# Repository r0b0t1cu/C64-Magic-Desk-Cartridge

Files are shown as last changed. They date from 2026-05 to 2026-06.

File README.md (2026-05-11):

# C64 Magic Desk Cartridge

An open-source hardware clone of the **Magic Desk** cartridge format for the Commodore 64. Supports both **27C512** (64KB) and **29F040** (512KB) EPROMs/EEPROMs, with bank switching handled by a classic 74LS273 + 74LS02 glue logic combination.

This board is designed to be built with through-hole components and DIP sockets, making it easy to assemble, reprogram, and experiment with.

| Front | Back |
|---|---|
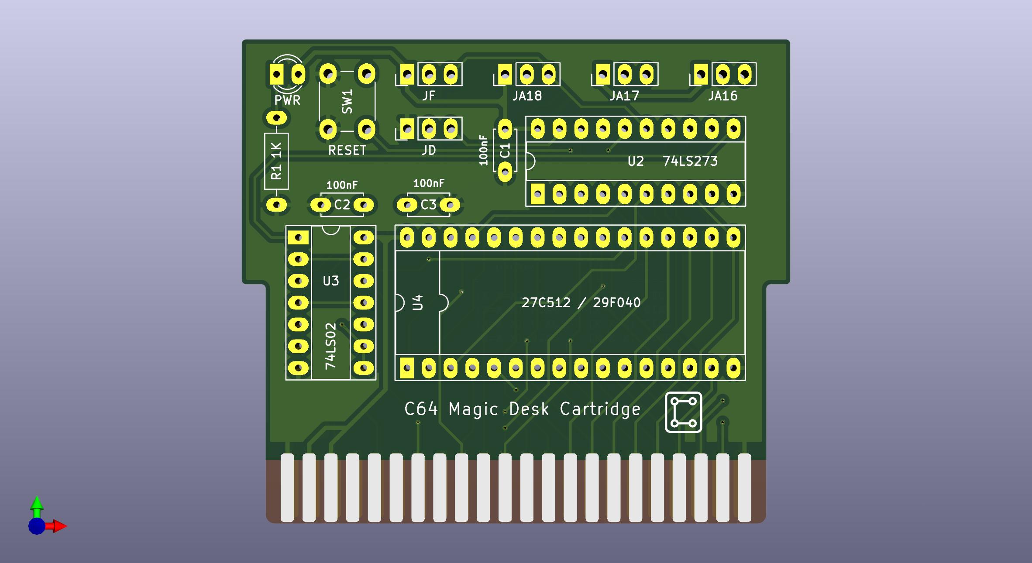
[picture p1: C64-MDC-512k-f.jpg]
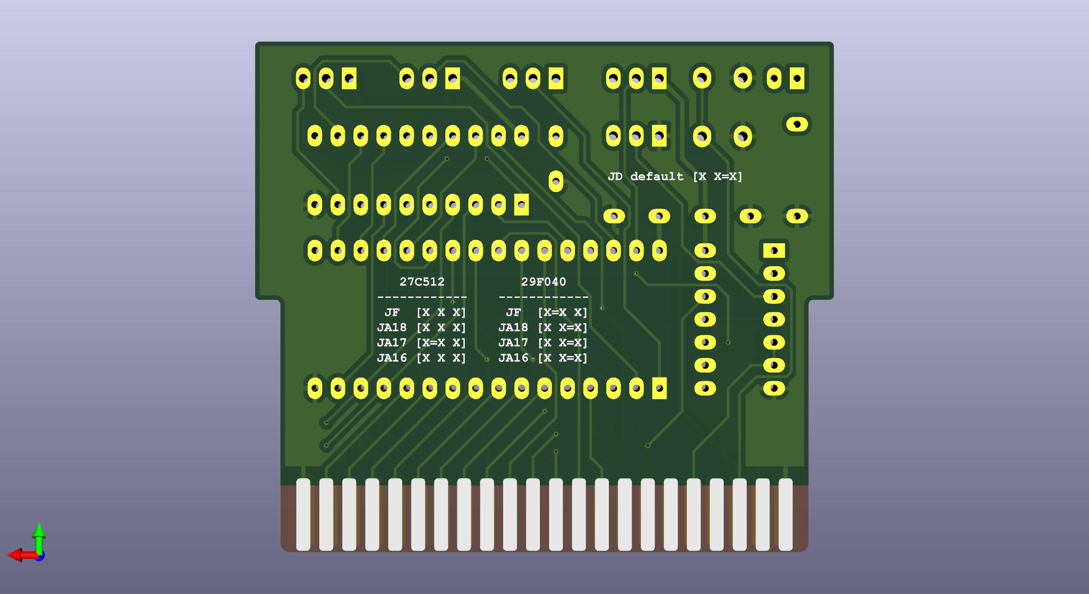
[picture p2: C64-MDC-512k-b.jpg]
|  |  |

---

## What is the Magic Desk Format?

Magic Desk is a simple and well-documented C64 cartridge format originally used by Commodore for titles like *Ghostbusters*, *Winter Games*, and others. It works by bank-switching 8KB ROM banks into the C64's memory map at `$8000`. A single byte write to `$DE00` selects the active bank; bit 7 controls the EXROM line to enable or disable the cartridge.
Because of its simplicity and wide software support, it became a popular format for homebrew multicarts and game compilations.

---

## Features

- Supports **27C512** (64KB) and **29F040** (512KB)
- Standard C64 cartridge edge connector
- DIP sockets for all ICs — easy to swap and reprogram
- PWR LED indicator
- RESET button
- Jumper configuration for ROM type

---

## Bill of Materials

| Ref | Qty | Value | Package |
|-----|-----|---|---|
| C1, C2, C3 | 3 | 100nF | Disc, 5.00mm pitch |
| R1 | 1 | 1K | Axial, horizontal |
| D1 | 1 | LED (PWR) | 3mm |
| U2 | 1 | 74LS273 | DIP-20, socket |
| U3 | 1 | 74LS02 | DIP-14, socket |
| U4 | 1 | 27C512 or 29F040 | DIP-32, socket |
| SW1 | 1 | RESET | Tactile push button 6mm |

---

## Jumper Configuration

The back of the board has a jumper table printed in silkscreen for quick reference. Configure the jumpers according to the ROM you are using:

### JD — default bank select (controls EXROM / cartridge enable)

| JD | Meaning |
|----|---|
| X X=X | Cartridge always enabled |

### Address line jumpers (JF, JA16, JA17, JA18)

These select which address lines are connected, depending on the ROM size installed.

#### 27C512 (64KB)

| Jumper | Setting |
|---|---|
| JF | X X X |
| JA18 | X X X |
| JA17 | X=X X |
| JA16 | X X X |

#### 29F040 (512KB)

| Jumper | Setting |
|---|---|
| JF | X=X X |
| JA18 | X X=X |
| JA17 | X X=X |
| JA16 | X X=X |

> **[X=X]** means the two pads are bridged with a solder jumper or jumper cap. **[X X X]** means left open.

Refer to the silkscreen on the back of the board for the full table.

---

## ROM Images

This repository includes pre-compiled **512KB `.bin` files** ready to be burned directly to a **29F040** EEPROM. Each image is a Magic Desk format multicart containing a curated selection of C64 software.

```
roms/
└── *.bin    # Ready-to-burn 512KB images for 29F040
```

To burn a `.bin` file to a 29F040, use a programmer such as:
- TL866II Plus / T48 (xgecu)
- GQ-4X
- Any EPROM programmer that supports the 29F040

| Front | Back |
|---|---|
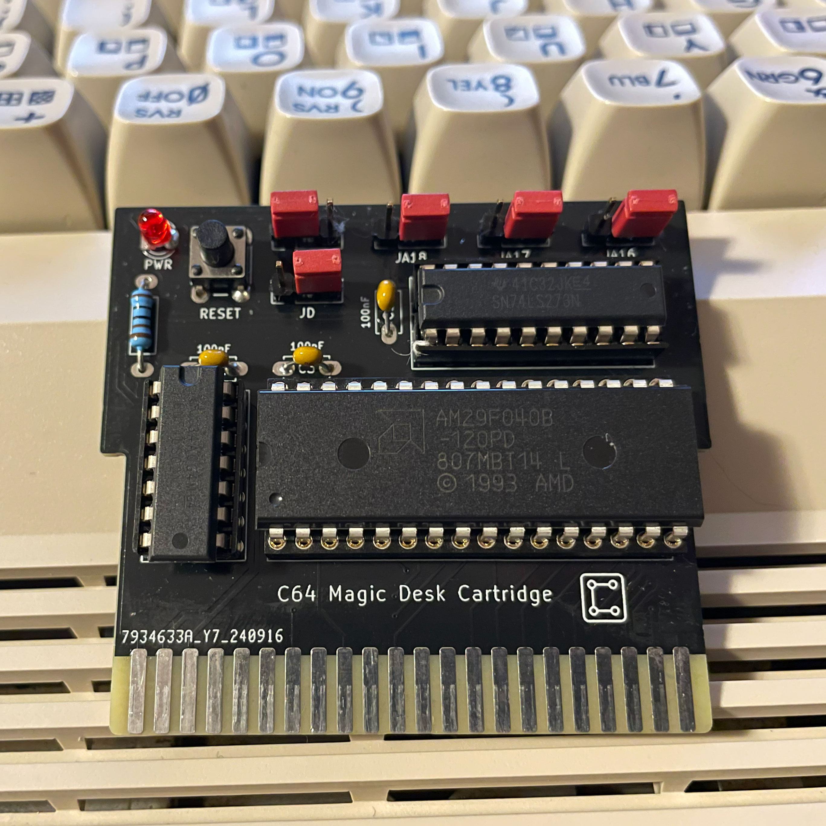
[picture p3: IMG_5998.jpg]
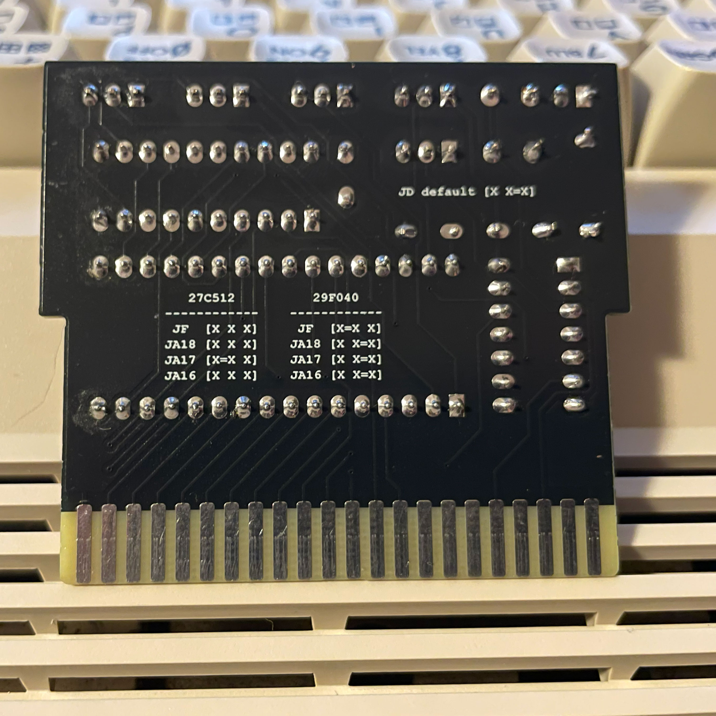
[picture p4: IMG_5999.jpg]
|  |  |

---

## Creating Your Own ROM Image

Use the **Magic Desk Cartridge Generator** by Zzarko to build your own `.bin` files from `.prg` or `.crt` files:

- [Magic Desk Cartridge Generator V3.0](https://csdb.dk/release/?id=179083) — original release
- [Magic Desk Cartridge Generator V3.5](https://csdb.dk/release/?id=205274) — newer version (recommended)
- [Source on Bitbucket](https://bitbucket.org/zzarko/magic-desk-cartridge-generator/)

The generator creates a menu-driven launcher that lets you select titles directly on the C64, with no extra hardware needed.

---

## Building the PCB

1. **Order the PCB** — use the Gerber files in `gerbers/`. Standard 2-layer 1.6mm FR4. JLCPCB, PCBWay, etc.
2. **Solder passives first** — capacitors, resistor, LED.
3. **Solder the edge connector** — take care with alignment; the card edge fingers go toward the bottom.
4. **Solder the DIP sockets** — do not solder ICs directly; use sockets so chips can be swapped.
5. **Configure jumpers** — set JF, JD, JA16, JA17, JA18 for your ROM type before inserting the chip.
6. **Insert ICs** — 74LS273, 74LS02, and your programmed EPROM/EEPROM.
7. **Insert into C64** — power on; the cartridge menu should appear immediately.

---

## Compatibility

Tested on:
- Commodore 64 (breadbin and short board)

Should work on:
- Commodore 64C
- Commodore 128 (in C64 mode)

---

## Related Projects

- [Magic Desk Cartridge Generator V3.5](https://csdb.dk/release/?id=205274) by Zzarko — the tool used to build the ROM images
- [Pi1541-Simple-HAT](https://github.com/r0b0t1cu/Pi1541-Simple-HAT) — Raspberry Pi HAT for Pi1541 disk emulation

---

## License

This project is open-source hardware released under the [CERN Open Hardware Licence v2 - Permissive (CERN-OHL-P)](https://ohwr.org/cern_ohl_p_v2.txt).

The Magic Desk Cartridge Generator is the work of Zzarko / Once Upon A Byte and is licensed separately.

---

## Author

Designed by [r0b0t1cu](https://github.com/r0b0t1cu) — 2026

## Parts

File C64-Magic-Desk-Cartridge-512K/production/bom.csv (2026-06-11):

Designator | Footprint | Quantity | Value | LCSC Part #
C1, C2, C3 | C_Disc_D4.7mm_W2.5mm_P5.00mm | 3 | 100nF
D1 | LED_D3.0mm | 1 | PWR
R1 | R_Axial_DIN0207_L6.3mm_D2.5mm_P10.16mm_Horizontal | 1 | 1K
SW1 | SW_PUSH_6mm | 1 | RESET
U1 | C64_Cart_Edge | 1 | C64 Cartridge Edge Connector
U2 | DIP-20_W7.62mm_Socket_LongPads | 1 | 74LS273
U3 | DIP-14_W7.62mm_Socket_LongPads | 1 | 74LS02
U4 | DIP-32_W15.24mm_Socket_LongPads | 1 | 27C512 / 29F040

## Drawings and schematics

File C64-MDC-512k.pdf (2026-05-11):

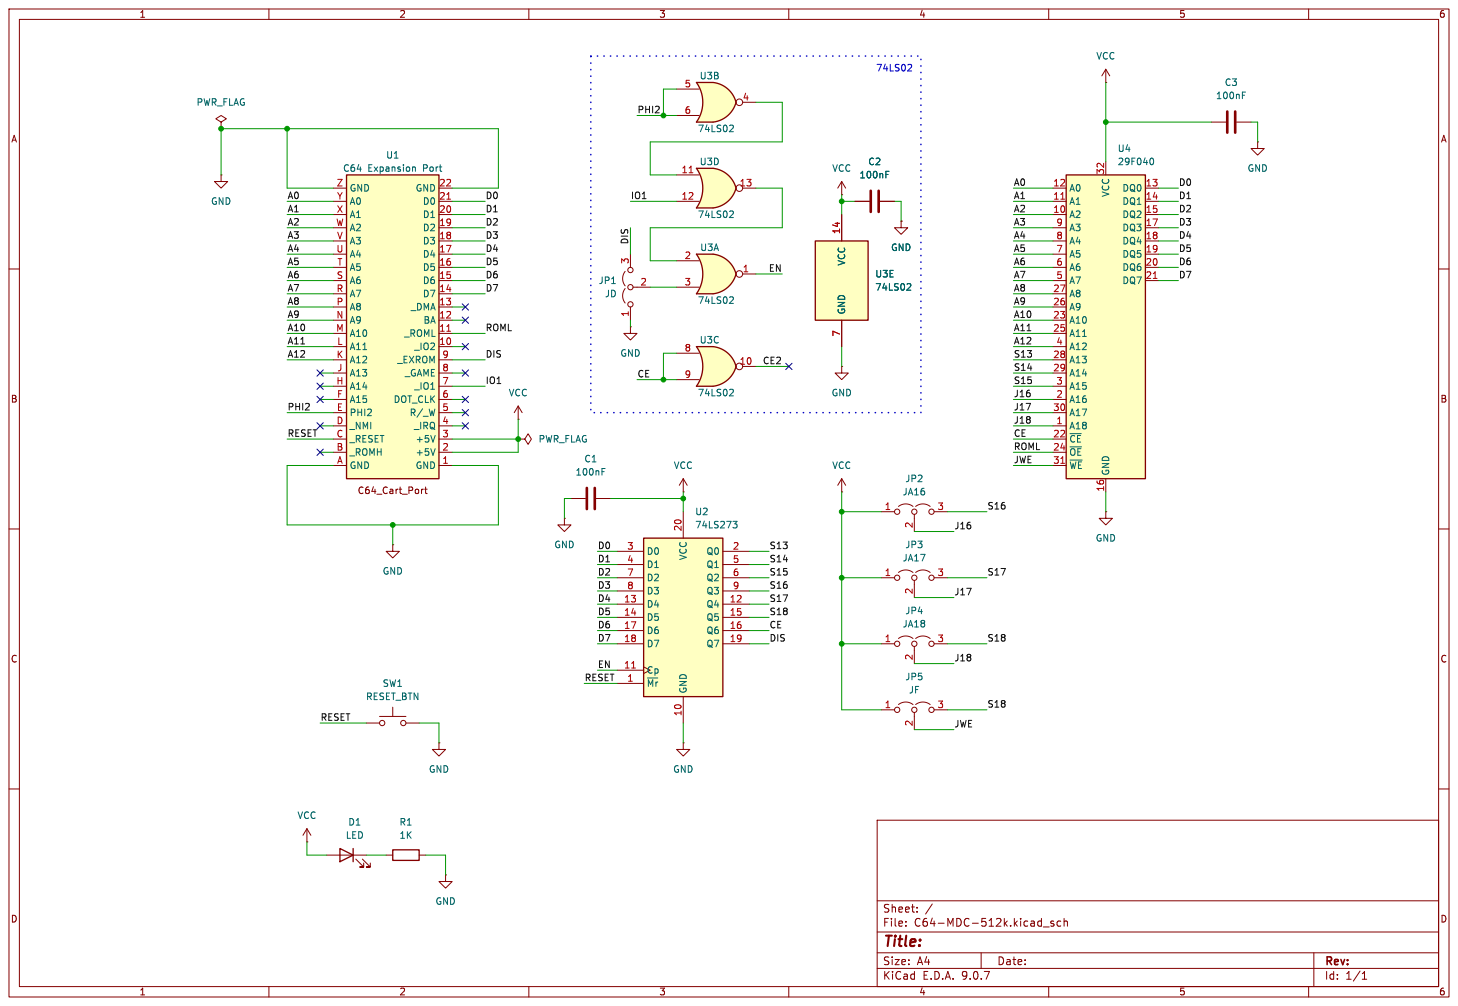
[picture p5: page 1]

Id: 1/1 Title: File: C64-MDC-512k.kicad_sch Sheet: /

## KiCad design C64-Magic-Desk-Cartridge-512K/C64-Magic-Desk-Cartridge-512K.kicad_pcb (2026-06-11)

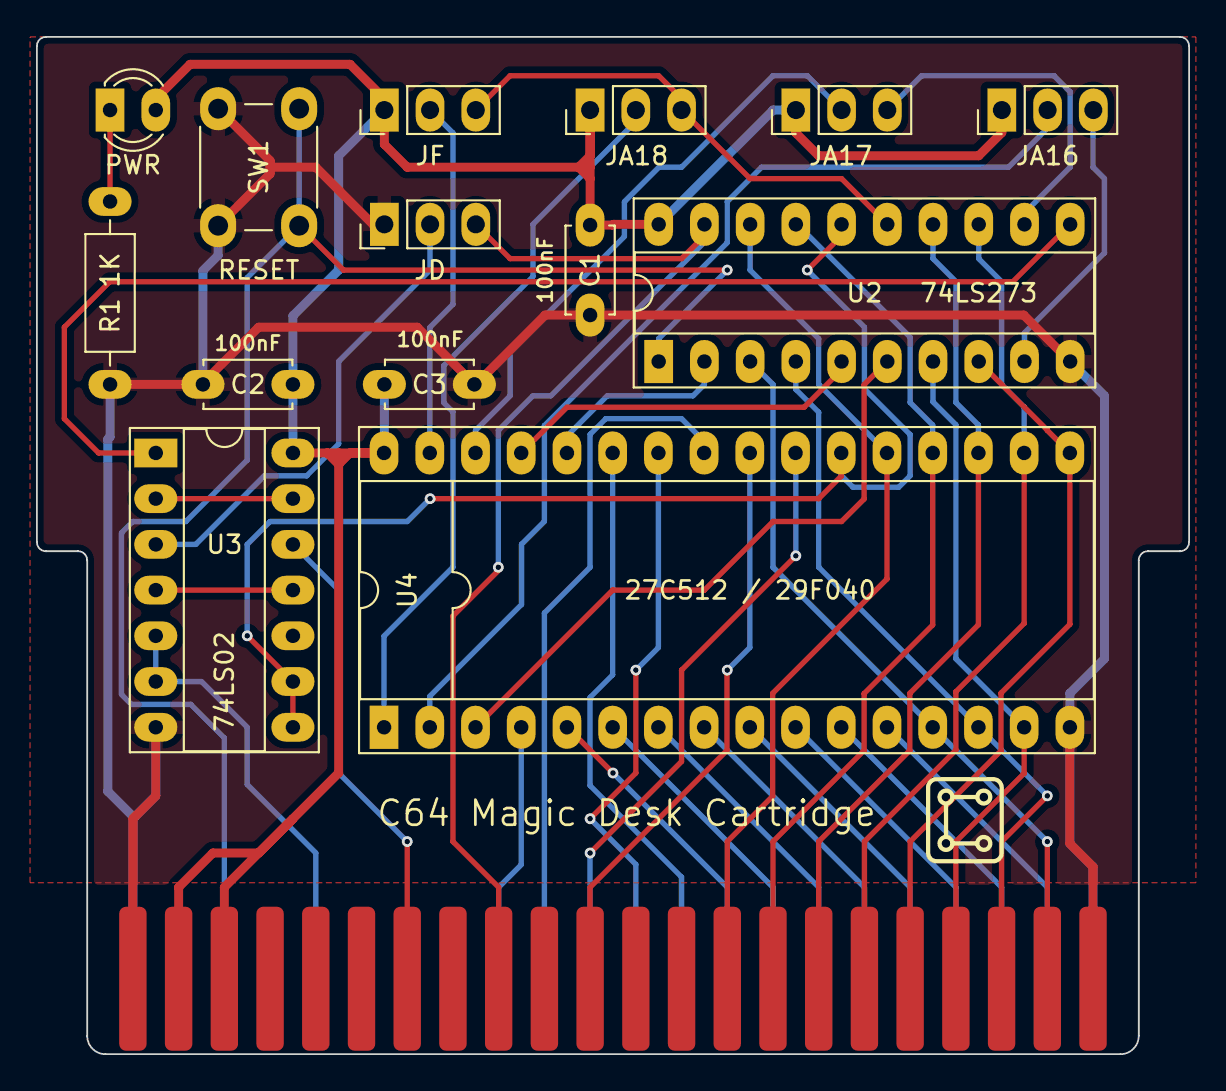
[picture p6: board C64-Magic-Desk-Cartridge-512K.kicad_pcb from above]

Board: 2 copper layers, 64.0 x 56.5 mm, 15 parts (0 on the bottom side), 44 nets.

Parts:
C1, C2, C3: 100nF; C_Disc_D4.7mm_W2.5mm_P5.00mm
D1: PWR; LED_D3.0mm
JP1: JD; PinHeader_1x03_P2.54mm_Vertical
JP2: JA16; PinHeader_1x03_P2.54mm_Vertical
JP3: JA17; PinHeader_1x03_P2.54mm_Vertical
JP4: JA18; PinHeader_1x03_P2.54mm_Vertical
JP5: JF; PinHeader_1x03_P2.54mm_Vertical
R1: 1K; R_Axial_DIN0207_L6.3mm_D2.5mm_P10.16mm_Horizontal
SW1: RESET; SW_PUSH_6mm
U1: C64 Cartridge Edge Connector; C64_Cart_Edge
U2: 74LS273; DIP-20_W7.62mm_Socket_LongPads
U3: 74LS02; DIP-14_W7.62mm_Socket_LongPads
U4: 27C512 / 29F040; DIP-32_W15.24mm_Socket_LongPads

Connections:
/A0: U1.Y (A0), U4.12 (A0)
/A1: U1.X (A1), U4.11 (A1)
/A2: U1.W (A2), U4.10 (A2)
/A3: U1.V (A3), U4.9 (A3)
/A4: U1.U (A4), U4.8 (A4)
/A5: U1.T (A5), U4.7 (A5)
/A6: U1.S (A6), U4.6 (A6)
/A7: U1.R (A7), U4.5 (A7)
/A8: U1.P (A8), U4.27 (A8)
/A9: U1.N (A9), U4.26 (A9)
/A10: U1.M (A10), U4.23 (A10)
/A11: U1.L (A11), U4.25 (A11)
/A12: U1.K (A12), U4.4 (A12)
/CE: U2.16 (Q6), U3.8, U3.9, U4.22 (~CE)
/D0: U1.21 (D0), U2.3 (D0), U4.13 (DQ0)
/D1: U1.20 (D1), U2.4 (D1), U4.14 (DQ1)
/D2: U1.19 (D2), U2.7 (D2), U4.15 (DQ2)
/D3: U1.18 (D3), U2.8 (D3), U4.17 (DQ3)
/D4: U1.17 (D4), U2.13 (D4), U4.18 (DQ4)
/D5: U1.16 (D5), U2.14 (D5), U4.19 (DQ5)
/D6: U1.15 (D6), U2.17 (D6), U4.20 (DQ6)
/D7: U1.14 (D7), U2.18 (D7), U4.21 (DQ7)
/DIS: JP1.3 (B), U1.9 (_EXROM), U2.19 (Q7)
/EN: U2.11 (Cp), U3.1
/IO1: U1.7 (_IO1), U3.12
/J16: JP2.2 (C), U4.2 (A16)
/J17: JP3.2 (C), U4.30 (A17)
/J18: JP4.2 (C), U4.1 (A18)
/JWE: JP5.2 (C), U4.31 (~WE)
/PHI2: U1.E (PHI2), U3.5, U3.6
/RESET: SW1.1, U1.C (_RESET), U2.1 (~Mr)
/ROML: U1.11 (_ROML), U4.24 (~OE)
/S13: U2.2 (Q0), U4.28 (A13)
/S14: U2.5 (Q1), U4.29 (A14)
/S15: U2.6 (Q2), U4.3 (A15)
/S16: JP2.3 (B), U2.9 (Q3)
/S17: JP3.3 (B), U2.12 (Q4)
/S18: JP4.3 (B), JP5.3 (B), U2.15 (Q5)
GND: C1.2, C2.2, C3.2, JP1.1 (A), R1.1, SW1.2, U1.1 (GND), U1.22 (GND), U1.A (GND), U1.Z (GND), U2.10 (GND), U3.7 (GND), U4.16 (GND)
unnamed: D1.1 (K), R1.2
unnamed: JP1.2 (C), U3.3
unnamed: U3.4, U3.11
unnamed: U3.2, U3.13
VCC: C1.1, C2.1, C3.1, D1.2 (A), JP2.1 (A), JP3.1 (A), JP4.1 (A), JP5.1 (A), U1.2 (+5V), U1.3 (+5V), U2.20 (VCC), U3.14 (VCC), U4.32 (VCC)
